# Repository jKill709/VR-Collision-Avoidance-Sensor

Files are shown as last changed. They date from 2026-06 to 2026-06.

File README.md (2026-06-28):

# VR-Collision-Avoidance-Sensor

This README describes the TARGET STATE of this repo.  The project as described is completed, but the documentation proccess is ongoing.  Until this message is removed, docouments listed as components of the repo may bve missing or otherwise missaligned.

## Overview
This repository documents the design and development of an embedded device intended to help VR users avoid physical collisions while immersed in virtual environments.

The project began as an Arduino-based prototype used to validate the core concept and functionality. It was then redesigned around the standalone ATmega328P microcontroller on a breadboard to explore a more integrated embedded implementation. The final iteration moved to a custom PCB design, creating a compact hardware platform suitable for further refinement toward a production-ready device.

The repository contains three documented development stages:

  - Arduino Prototype: Rapid proof-of-concept development using the Arduino platform
  - ATmega328P Breadboard Version: Standalone microcontroller implementation with custom firmware and supporting circuitry
  - Custom PCB Version: Dedicated hardware design including schematics, PCB layout, and final firmware

Each stage includes hardware documentation, firmware, design decisions, and lessons learned throughout the development process.

## Key Features
- Based on ATmega328P using 
- HC-SR04 Ultrasound distance sensor to sense distance to obsticals
- LED and speaker output alerts user
- Final Version has on-board Li-on battery with HW-107 charging module

## Architecture Diagram
```text
VR-Collision-Avoidance-Sensor/
│
├── README.md
├── LICENSE
├── .gitignore
├── arduino_version/
│   ├── README.md
│   ├── src/
│   │   └── Wall_Sensor_0.1.3.ino
│   │   │
│   ├── hardware/
│   │   ├── Circut_Map.png
│   │   └── bom.csv
│   │   
│   └── images/
│       └── various images 
│
├── atmega_breadboard_version/
│   ├── README.md
│   ├── firmware/
│   │   └── BattleBuddy_S_0.1.ino
│   │
│   ├── hardware/
│   │   └── bom.csv
│   │   
│   └── images/
│       └── various images 
│   
│
└── pcb_version/
    ├── README.md
    ├── firmware/
    │   └── Wall_Sensor_0.2.0
    │   
    ├── hardware/
    │   ├── bom.csv
    │   │
    │   └── pcbway_files/
    │       └── various manufacturing assets for PCBway.com
    └── images/
        └── various images 
 ```

## Project Stages

See each stage's README for details:

- Arduino Prototype:  `arduino_version\README.md`
Arduino Prototype
- Breadboard Bare-Metal Implementation:  `atmega_breadboard_version\README.md`
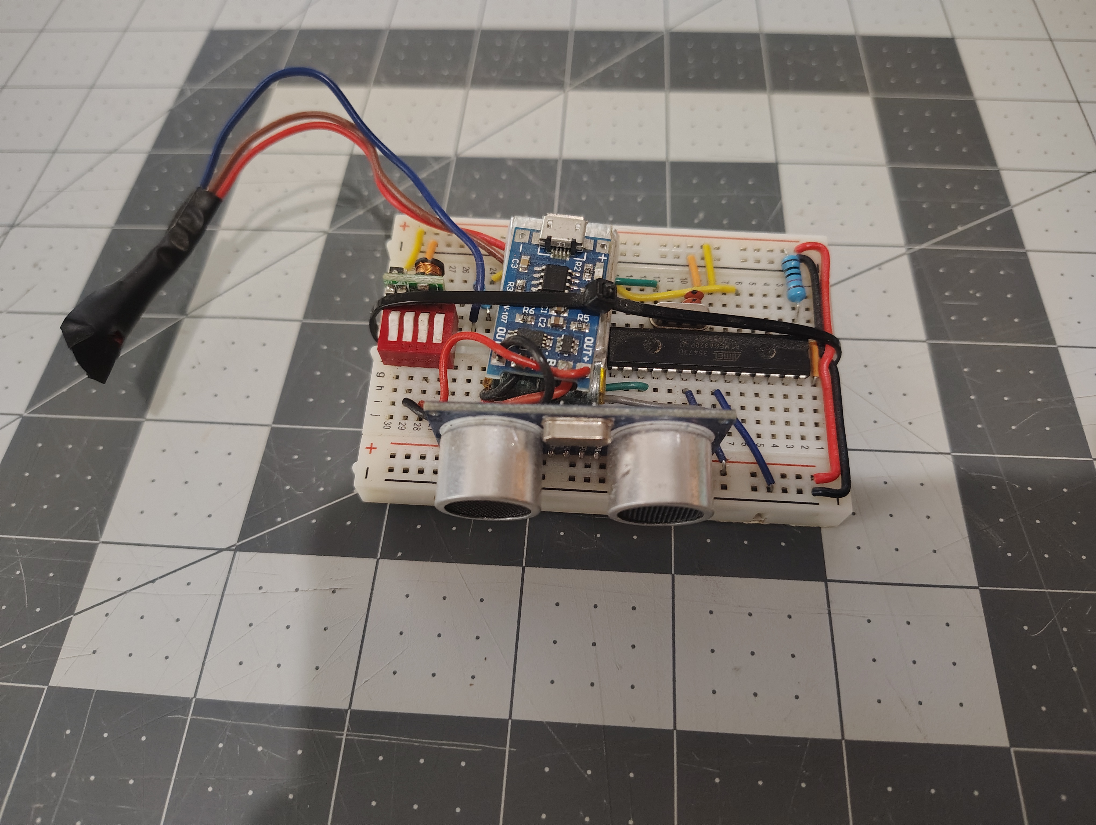
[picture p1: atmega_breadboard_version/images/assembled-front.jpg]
Breadboard Prototype

- PCB Production Prototype Version:  `pcb_version\README.md`
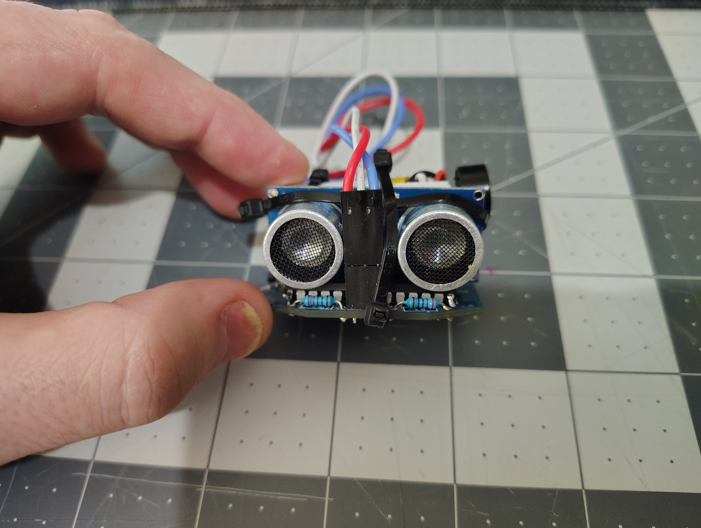
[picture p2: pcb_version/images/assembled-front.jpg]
PCB Prototype


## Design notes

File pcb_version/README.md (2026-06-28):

# Atmega-Breadboard Wall Sensor - "Wall Sensor 0.2"

Arduino Prototype

## Purpose

Build on previous work to create an improved embedded prototype for preventing physical collisions while using VR headsets.

This prototype combines the lessons learned from the Battle Buddy prototype by adding a more complete warning system:

- Visual distance indication using RGB LED feedback
- Audible proximity warning
- Embedded microcontroller design
- Battery-powered operation

This version validates the combined feedback system and transitions to a custom PCB implementation.

---

## Architecture

- Ultrasonic sensor module (HC-SR04) to measure distance
- RGB LED to provide visual feedback based on object proximity
- Piezoelectric buzzer to provide audible proximity warnings
- Atmega328P microcontroller for logic and control
- Li-ion battery for wireless operation
- HW-107 Battery Management Module for charging
- Boost converter to provide regulated 5V operation

The warning system converts distance measurements into a warning intensity value:

- Far distance:
  - Blue LED indication
  - No buzzer

- Medium distance:
  - Color transitions toward red
  - Intermittent warning tone

- Close distance:
  - Red LED indication
  - Maximum warning intensity

---

## Hardware

### Components

| Item | Qty | Reference | Value | Description | Part Number |
|:---|:---:|:---:|:---:|:---|:---|
| 1 | 1 | U1 | | Microcontroller | Atmega328P |
| 2 | 1 | X1 | | Piezoelectric Oscillator | |
| 3 | 2 | C1 C2 | 22 pF | Ceramic Capacitor | |
| 4 | 1 | HC-SR04 | | Ultrasonic Sensor | HC-SR04 |
| 5 | 1 | R1 | 10K Ohms | Resistor | |
| 6 | 1 | D1 | 5V | RGB LED | |
| 7 | 2 | R2 R3 | 220 Ohms | Current-Limiting Resistor | |
| 8 | 1 | PCB | | Custom PCB | |
| 9 | 1 | Boost | 3V to 5V | Boost Converter | |
| 10 | 1 | S1 | | Power Switch | |
| 11 | 1 | HW-107 | | Battery Management Module | HW-107 |
| 12 | 1 | B1 | 3.7V 300 mAh | Li-ion Battery | |
| 13 | 2 | J1 J2 | 2.54mm 2x1 | Header Pins | |
| 14 | 1 | J3 | 2.54mm 3x1 | Header Pins | |
| 15 | 1 | | 2.54mm 2x1 | Male Dupont Connector with Pins | |
| 16 | 1 | | 2.54mm 3x1 | Male Dupont Connector with Pins | |

---

### Hardware Documentation

- Circuit diagram: `hardware/Circuit_Map.png`
- Bill of materials: `hardware/BOM.csv`
- Image of materials: `images/parts-staged.jpg`

---

## Software

The Arduino firmware:

- Runs startup LED sequence to indicate operation
- Reads distance measurements from the HC-SR04 sensor
- Converts measured distance into warning intensity
- Controls RGB LED color and brightness
- Activates buzzer warning based on proximity

Firmware location:  ```firmware/Wall_Sensor_0.2.0/Wall_Sensor_0.2.0.ino```

---

## Design Notes

This version combines the visual feedback concepts explored in Battle Buddy with the warning behavior from the original Wall Sensor prototype.

Changes:

- Uses bare Atmega328P microcontroller instead of Arduino UNO R3
- Adds battery operation with USB charging
- Reintroduces audible warnings for improved situational awareness
- Replaces simple LED indication with RGB distance feedback
- Uses warning intensity as a shared value for multiple output systems

The warning intensity model allows the system to scale naturally:

```
Distance
|
v
Warning Intensity
|
+--> RGB LED
|
+--> Buzzer
```

---

## Limitations

- Detection is limited to a single ultrasonic sensor direction
- Sensor placement and field-of-view limit detection coverage
- LED indication through VR headset optics is functional but not optimized
- Needs a proper enclosure and attatchment mechanism

---

## Lessons Learned

This prototype validated:

- RGB visual feedback provides better distance awareness than simple alarms
- Combining visual and audible feedback improves user awareness
- Bare microcontroller design works for a wearable embedded device
- The design direction is suitable for continued development toward a custom PCB implementation
- The LED used was too small, leading to a structural failure of the solder joints.  Need a better design, oir more skilled solder opperator.

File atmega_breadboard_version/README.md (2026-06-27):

# Atmega-Breadboard Wall Sensor -  "The Battle Buddy"

Arduino Prototype

## Purpose

Build on previous work to create usable prototype of an embedded device to prevent physical collisions while using VR headsets.

This prototype was developed to validate the off-the-shelf modules and design used for this embedded device before transitioning to a Custom PCB implementation.

---

## Architecture

- Ultrasonic sensor module (HC-SR04) to measure distance
- Red and blue LEDs to alert the VR user of detected objects and the estimated distance
- LEDs are ran non destructivly to the optical cavity of the VR headset for user indication
- atmega328p microcontroller for logic and control
- Li-on Battery for wireless operation
- HW-107 Battery Management Module for charging

---

## Hardware

### Components

| Item | Qty | Reference | Value | Description |
|:---|:---:|:---:|:---:|:---|
| 1 | 1 | U1 |  | Microcontroller |
| 2 | 1 | X1 |  | Piezoelectric Oscillator |
| 3 | 2 | C1 C2 | 22 pF | Ceramic Capacitor |
| 4 | 1 | HC-SR04 |  | Ultrasonic Sensor |
| 5 | 1 | R1 | 10K Ohms | Resistor |
| 6 | 1 | D1 | 5V | RGB LED |
| 7 | 2 | R2 R3 | 220 Ohms | Current-Limiting Resistor |
| 8 | 1 |  | 400 Tie-Points | Breadboard |
| 9 | 1 | Boost | 3V to 5V | Boost Converter |
| 10 | 1 | S1 |  | Power Switch |
| 11 | 1 | HW-107 |  | Battery Management Module |
| 12 | 1 | B1 | 3.7V 300 mAh | Li-ion Battery |

### Hardware Documentation

- Circuit diagram: `hardware/Circuit_Map.png`
- Bill of materials: `hardware/BOM.csv`
- Image of materials: `images/parts-staged.jpg`

---

## Software

The Arduino firmware:

- Startup sequence to indicate function
- Reads distance measurements from the HC-SR04 sensor
- Activates visual alerts when an object is detected

Firmware location:

```
<!-- firmware/BattleBuddy_S_0.1/BattleBuddy_S_0.1.ino -->
```

---

## Design Notes

This version focuses on design validation before committing to a PCB design.

Changes:
- Uses bare microprocessor instead of Arduino UNO R3
- Adds battery operation with USB charging, allowing alpha testing
- Swaps buzzer for a more nuanced LED signaling system: uses 2 colors to show distance to detection

Limitations:
- Only breadboarded, so not rugged enough for beta testing
- Only shows detection in current direction
- Not optimized for a final embedded product
- Sub-optimal switch choice.  I used what I had.
- Indicator LED is run nondestructively, but this is not the best user experience  (see `images/indicator-installed.png`)

---

## Lessons Learned

This prototype validated:

- Can perform it's basic function in actual use (Alpha testing was successful!)
- Bare microprocessor design works
- Warning feedback mechanisms were improved
- Suitable for wearing as a VR headset accessory

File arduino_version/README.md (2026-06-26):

# Arduino-Based Wall Sensor

Arduino Prototype

## Purpose

Use the Arduino microcontroller development platform to investigate the creation of an embedded device to prevent physical collisions while using VR headsets.

This prototype was developed to validate the core concept before transitioning to a standalone ATmega328P implementation.

---

## Architecture

- Ultrasonic sensor module (HC-SR04) to measure distance
- LED and passive speaker to alert the VR user of detected objects
- Arduino UNO R3 for logic and control
- Potentiometer to adjust detection sensitivity for development
- Serial output over USB for validation and debugging

---

## Hardware

### Components

| Item | Qty | Reference | Value | Description |
|:---|:---:|:---:|:---:|---:|
| 1 | 1 |  |  | Arduino UNO R3 Development Board |
| 2 | 1 | HC-SR04 |  | Ultrasonic Sensor |
| 3 | 1 | BZ1 |  | Passive Buzzer |
| 4 | 1 | D1 | 5V | Green LED (ON/OFF Indicator) |
| 5 | 1 | D2 | 5V | Red LED (Warning LED) |
| 6 | 1 | Pot1 | 10K Ohms | Potentiometer |
| 7 | 2 | R1, R2 | 220 Ohms | Current-Limiting Resistor|
| 8 | 1 |  | 170 Tie-Points | Breadboard |

### Hardware Documentation

- Circuit diagram: `hardware/Circuit_Map.png`
- Bill of materials: `hardware/BOM.csv`

---

## Software

The Arduino firmware:

- Reads distance measurements from the HC-SR04 sensor
- Compares distance against an adjustable warning threshold
- Activates visual and audible alerts when an object is detected
- Provides serial output for testing and calibration

Firmware location:

```
src/Wall_Sensor_0.1.3.ino
```

---

## Design Notes

This version prioritized rapid development and concept validation.

Advantages:
- Fast iteration using the Arduino ecosystem
- Easy debugging through USB serial output
- Minimal hardware setup

Limitations:
- Requires power cord
- Dependent on Arduino development board
- Not optimized for a final embedded product

---

## Lessons Learned

This prototype validated:

- Ultrasonic sensing was suitable for collision detection
- Warning feedback mechanisms were effective
- A standalone microcontroller implementation was feasible
- A threshold value was determined by using potentiometer and serial output, and can now be hardcoded in the next iteration

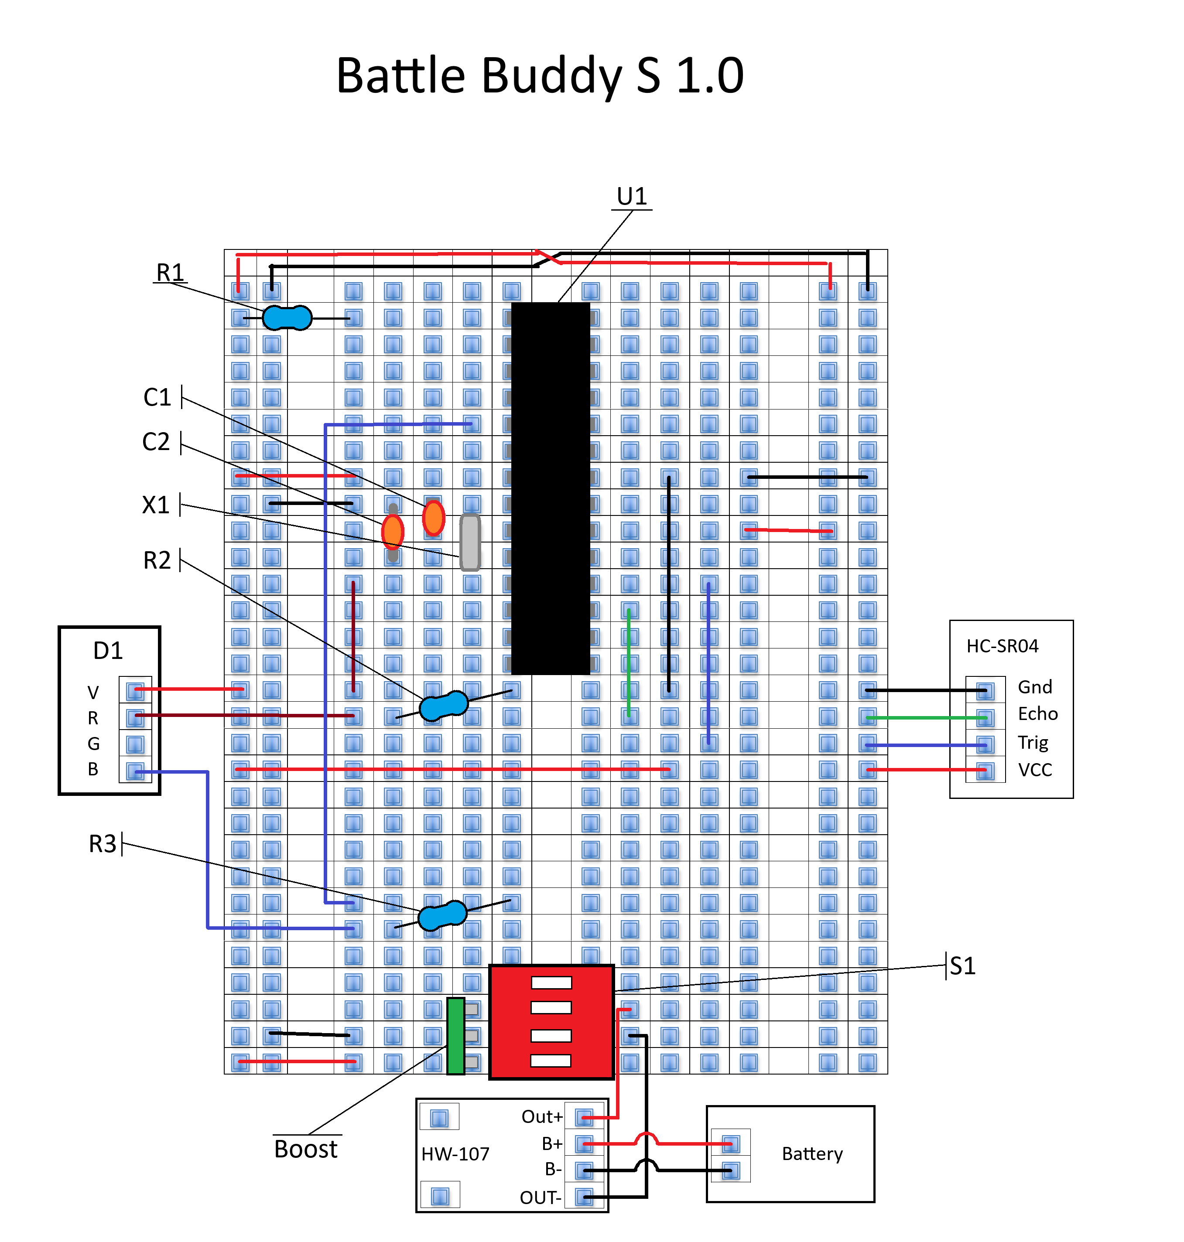
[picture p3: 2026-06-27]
atmega_breadboard_version/hardware/circut-map.png

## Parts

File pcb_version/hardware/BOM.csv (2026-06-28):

Item | Qty | Reference | Value | Description | Part Number
1 | 1 | U1 |  | Microcontroller | Atmega328P
2 | 1 | X1 |  | Peizioelectric Oscilator
3 | 2 | C1 C2 | 22 pF | Ceramic Capacitor
4 | 1 | HC-SR04 |  | Ultrasonic Sensor | HC-SR04
5 | 1 | R1 | 10K Ohms | Resisitor
6 | 1 | D1 | 5V | RGB LED
7 | 2 | R2 R3 | 220 Ohms | Current-Limiting Resistor
8 | 1 | PCB |  | Custom PCB
9 | 1 | Boost | 3v to 5 v | Boost Converter
10 | 1 | S1 |  | Power Switch
11 | 1 | HW-107 |  | Battery Management Module | HW-107
12 | 1 | Battery | 3.7 v 300 mAh | Li-ion Battery
13 | 2 | J1 J2 | 2.45mm 2x1 | Header Pins
14 | 1 | J3 | 2.45mm 3x1 | Header Pins
15 | 1 |  | 2.45mm 2x1 | Male Dupont Connector w/ Pins
16 | 1 |  | 2.45mm 3x1 | Male Dupont Connector w/ Pins

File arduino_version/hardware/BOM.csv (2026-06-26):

Item | Qty | Reference | Value | Description | Part Number | Notes
1 | 1 |  |  | Arduino UNO R3 Development Board
2 | 1 | HC-SR04 |  | Ultrasonic Sensor | HC-SR04
3 | 1 | Buzzer |  | Passive Buzzer
4 | 1 | D1 | 5V | Green LED |  | ON/OFF Indicator
5 | 1 | D2 | 5V | Red LED |  | Warning LED
6 | 1 | Pot1 | 10K Ohms | Potentiometer
7 | 2 | R1 R2 | 220 Ohms | Current-Limiting Resistor
8 | 1 |  | 170 Tie-Points | Breadboard

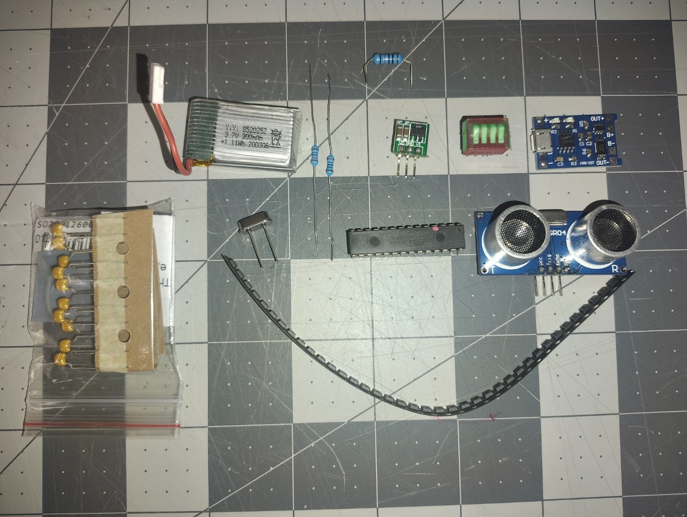
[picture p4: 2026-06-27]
atmega_breadboard_version/images/parts-staged.jpg

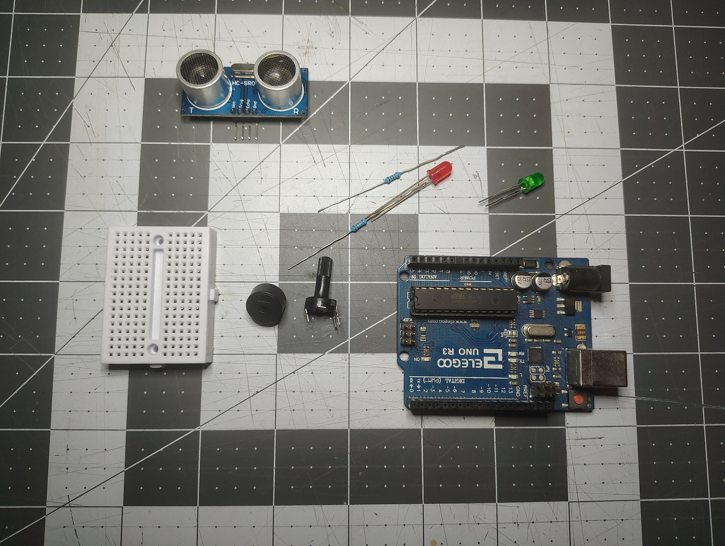
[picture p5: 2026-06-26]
arduino_version/images/parts-staged.jpg

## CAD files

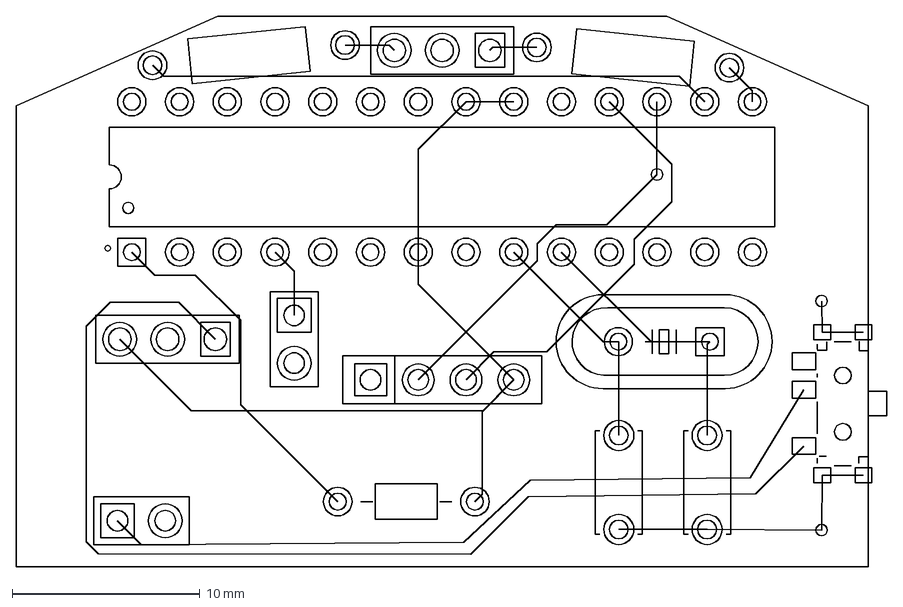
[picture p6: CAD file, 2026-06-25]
pcb_version/hardware/pcbway_files/Board Model v1.dxf
46.3 x 29.3 mm

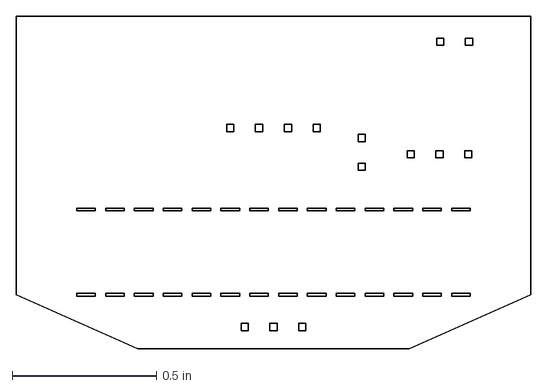
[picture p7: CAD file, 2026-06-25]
pcb_version/hardware/pcbway_files/Board.dxf
1.79 x 1.15 in

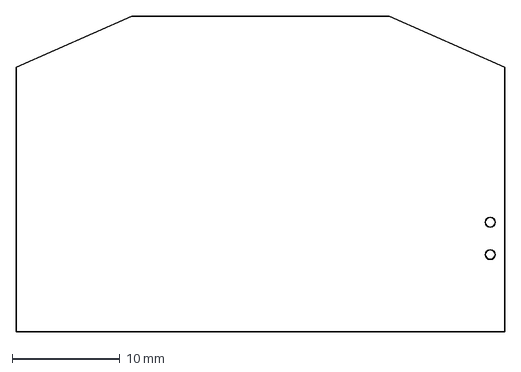
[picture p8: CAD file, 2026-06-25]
pcb_version/hardware/pcbway_files/Board Model, Holes v1.dxf
45.3 x 29.3 mm

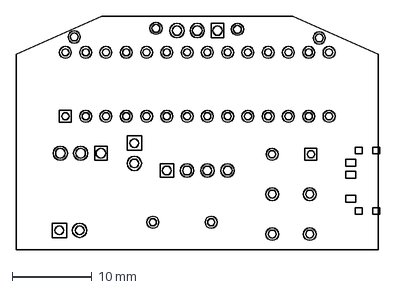
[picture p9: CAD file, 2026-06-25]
pcb_version/hardware/pcbway_files/Board Model, Copper v1.dxf
45.5 x 29.3 mm

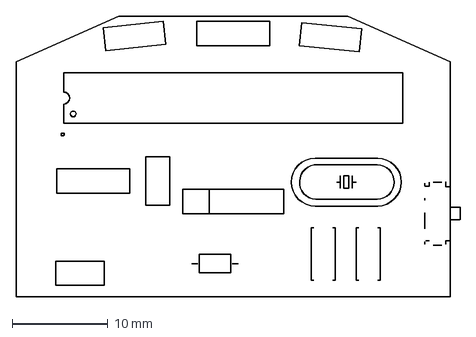
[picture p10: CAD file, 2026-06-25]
pcb_version/hardware/pcbway_files/Board Model, Silkscreen v1.dxf
46.3 x 29.3 mm

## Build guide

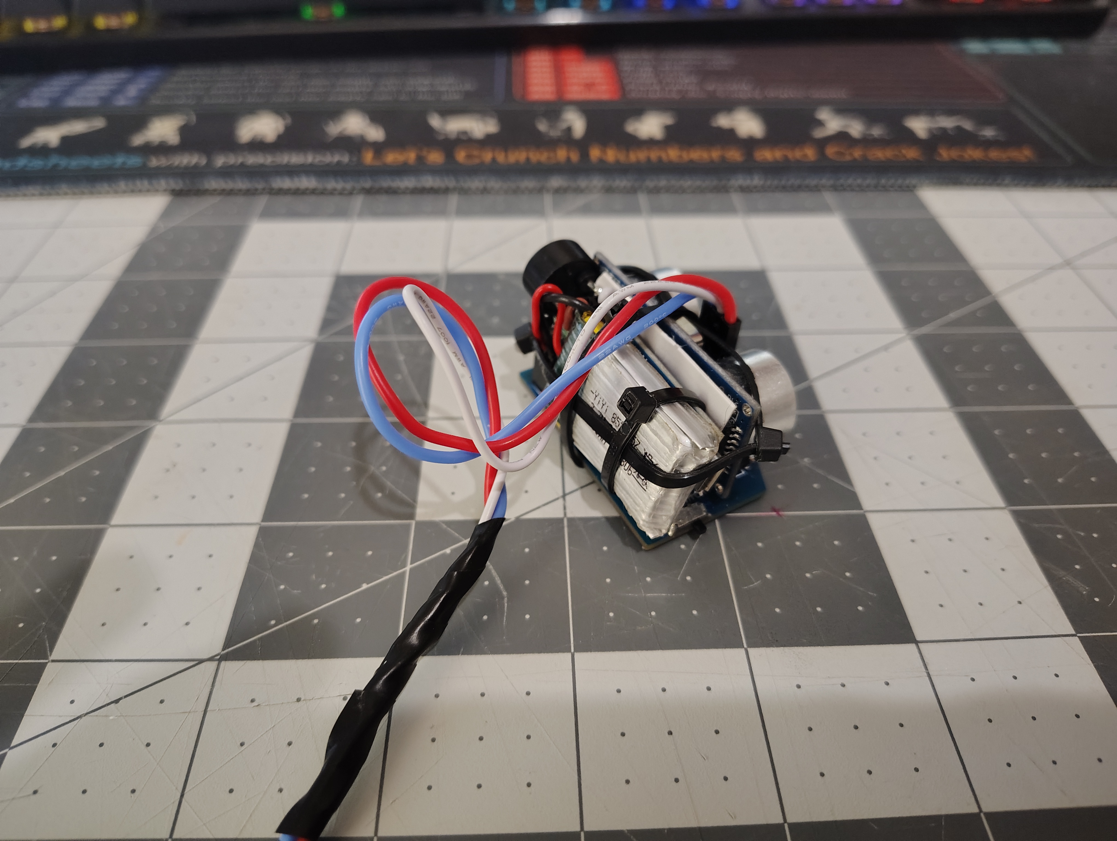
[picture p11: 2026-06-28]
pcb_version/images/assembled-rear-2.jpg

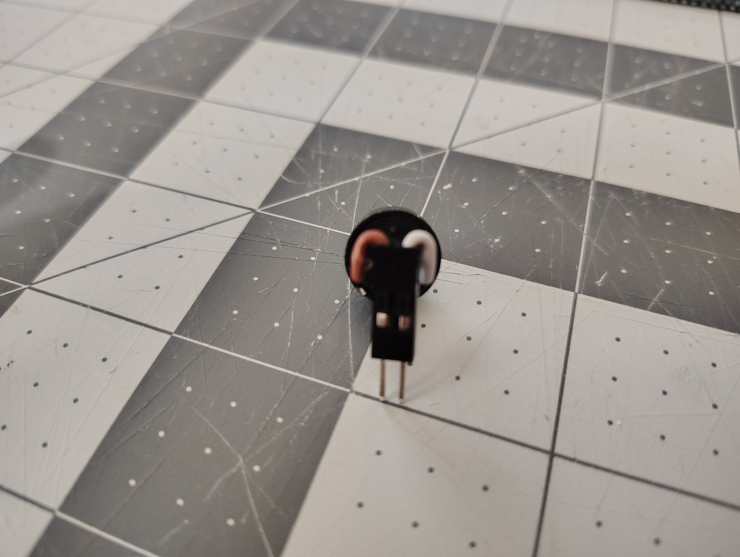
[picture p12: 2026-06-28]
pcb_version/images/speaker-subassembly-rear.jpg

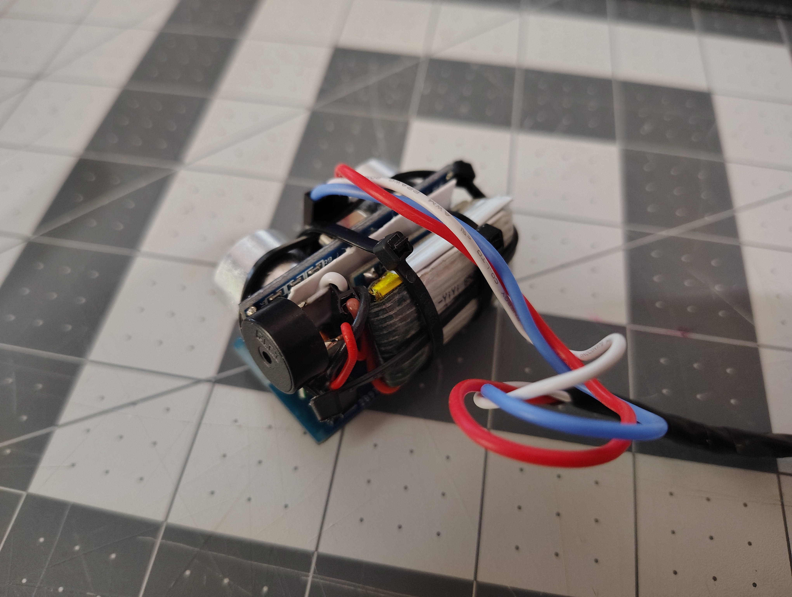
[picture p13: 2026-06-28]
pcb_version/images/assembled-rear-1.jpg

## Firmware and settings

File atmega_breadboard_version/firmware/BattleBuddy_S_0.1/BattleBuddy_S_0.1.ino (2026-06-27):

/*      Wall Sensor v0.1.04
 *      
 *      Last Modified 1/10/20
 *
 *      Ultrasonic proximity sensor with RGB LED visual feedback.
 *      As an object approaches, the LED intensity increases.
 *      Includes startup animation sequence.
 */

#include <SPI.h>
#include <Wire.h>


// Pin Numbers            
#define redLED 5          // Red LED Pin          | Must Be PMW
#define blueLED 3         // Blue LED Pin         | Must Be PMW
#define sensorTrig 12     // HC-SR04 Trigger Pin  | no requirements
#define sensorEcho 11     // HC-SR04 Echo Pin     | no requirements

// System Settings
#define distMin 30                // Min distance for LED fade, in cm
#define distMax 64                // Max distance for LED fade, in cm
#define maxIntensity 0.125 * .6   // Maximum LED brightness scaling factor.  Could be replaced with larger resistor than BOM spec.
#define cycleTime 50              // Sensor update interval in milliseconds

// Sensitivity multiplier used to adjust effective sensor range
float sensitivity = 1.00;

// Loop Control
// Stores the next time the sensor should be sampled
long nextCycleTime;

// 
//
// Setup
void setup() {  

  // Configure LED pins as outputs
  pinMode(redLED, OUTPUT);
  pinMode(blueLED, OUTPUT);
  pinMode(sensorTrig, OUTPUT);
  pinMode(sensorEcho, INPUT);

  // Configure ultrasonic sensor pins
  introSeq();
    

  // Schedule first sensor reading
  nextCycleTime = millis() + cycleTime;
}

//
//
// Main Loop
void loop() {

  // Timing control.  Only samples the sensor after cycleTime has elapsed.
  if(millis() >= nextCycleTime) {

    // Schedule next sensor reading
    nextCycleTime = millis() + cycleTime;

    // Read distance and update LED output
    sampleSensor();
  }
}

//
//
// Converts distance value into LED intensity value
//
// Close distance  = brighter LED
// Far distance    = dimmer LED
//
// Returns PWM value from 0-255
int distanceToIntensity(long distance) {

  // Maps measured distance range into LED brightness range
  // constrain prevents values outside the valid PWM range
  return constrain(map(distance, distMin * sensitivity, distMax * sensitivity, 255 * maxIntensity, 0), 0, 255 * maxIntensity);
}

//
//
//  Reads ultrasonic sensor and updates LED brightness
void sampleSensor() {

  // Send ultrasonic trigger pulse
  digitalWrite(sensorTrig, LOW);
  delayMicroseconds(2);

  digitalWrite(sensorTrig, HIGH);
  delayMicroseconds(10);

  digitalWrite(sensorTrig, LOW);
  delayMicroseconds(2);

  // Measure echo return time and convert to distance
  // pulseIn returns microseconds
  // Conversion factor converts time into centimeters
  //
  // LED brightness is inverted:
  // closer object = higher intensity
  // farther object = lower intensity
  analogWrite(redLED, 255 - (distanceToIntensity(pulseIn(sensorEcho, HIGH, 400000) * (100.00 / 5882.00))));
}

//
//
// Intro Sequence
//
//    A/V sequence for flashy bootup
void introSeq() {

  // Turn on red LED
  analogWrite(redLED, 255);

  // Turn off blue LED
  analogWrite(blueLED, 0);

  delay(200);

  // Turn on blue LED
  analogWrite(blueLED, 255);

  delay(800);

  // Fade both colors down
  for (int i = 0; i < 256; i++) {

    // Gradually reduce LED intensity
    analogWrite(redLED, 255 - i/16);
    analogWrite(blueLED, 255 - i);
    
    delay(3);
  }

  // Leave LEDs fully illuminated after startup
  analogWrite(redLED, 255);
  analogWrite(blueLED, 255);  
}

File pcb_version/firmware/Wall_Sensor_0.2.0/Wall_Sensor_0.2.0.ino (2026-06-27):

#include <SR04.h>
#include <pitches.h>

/*      Wall Sensor v0.1.04
 *      
 *      Last Modified 1/24/19
 *
 *      Ultrasonic proximity warning system.
 *      Uses distance measurement to control:
 *      - RGB LED warning intensity
 *      - Audible buzzer feedback
 *
 *      As an object approaches:
 *      - LED color shifts from blue toward red
 *      - Warning tone increases in duration
 */
 
// Pin Numbers
#define redLED 9          // Red LED Pin          | Must Be PMW
#define blueLED 10        // Blue LED Pin         | Must Be PMW
#define warningBuzzer 2   // Buzzer Pin           | no requirements
#define ussTrigPin 12     // HC-SR04 Trigger Pin  | no requirements
#define ussEchoPin 11     // HC-SR04 Echo Pin     | no requirements

// System Settings
int threshold = 122;      // Distance at which warning begins, in cm
int cycleTime = 100;      // Main update cycle time, in ms

// Instantiate Sensor Object
SR04 usSensor = SR04(ussEchoPin,ussTrigPin);

//
//
// Setup
void setup() {  

  // Configure output pins
  pinMode(redLED, OUTPUT);
  pinMode(blueLED, OUTPUT);
  pinMode(warningBuzzer, OUTPUT);

  // Run startup LED animation
  introSeq();
}

//
//
// Intro Sequence
//
//    A/V sequence for flashy bootup
void introSeq() {

  // Start with blue LED fully on
  analogWrite(redLED, 0);
  analogWrite(blueLED, 255);

  delay(200);

  // Turn blue off
  analogWrite(blueLED, 0);

  delay(800);

  // Fade blue LED back in
  for (int i = 0; i < 256; i++) {
    analogWrite(blueLED, i);
    delay(3);
  }
  
}

//
//
// beepCalc
//
//    Return a float between 0 and 1 indicating how much of each 
//    cycle should be spent with the buzzer on
//
//    0 = no warning
//    1 = continuous warning
//
//    Warning increases as distance decreases
float beepCalc (float dist, float threshold) {

  // Distance ratio relative to warning threshold
  float a = dist/threshold;

  // Maximum warning when object is closer than half threshold
  if (dist < .5 * threshold) {
    return 1;

  // No warning when outside threshold distance
  } else if (dist > threshold) {
    return 0;

  // Scale warning intensity between half threshold and threshold
  } else {
    return pow((-2 * dist/threshold) + 2, 1);   //<-- WTF? X^1?
  }
}

//
//
//  lightAdj
//
//  Set the color of the LED based on warningInstensity
//
// warningIntensity:
// 0 = blue / no warning
// 1 = red / maximum warning
//
// Adjusts both active and inactive LED channels
void lightAdj(float warningIntensity) {

  int onLightPin;
  int offLightPin;

  int onLightVal;
  int offLightVal;


  // Calculate brightness of active LED channel
  onLightVal = 255 * (0.8 * (pow(warningIntensity * 2 - 1, 4)) + 0.2);

  // Calculate brightness of inactive LED channel
  offLightVal = 255 * ((-pow(warningIntensity - 0.5, 2) * 5) + 0.2);


  // Prevent negative PWM values
  if (offLightVal < 0) {
    offLightVal = 0;
  }


  // Select LED color based on warning intensity
  if (warningIntensity > .5) {

    // Higher warning = red dominant
    onLightPin = redLED;
    offLightPin = blueLED;

  } else {

    // Lower warning = blue dominant
    onLightPin = blueLED;
    offLightPin = redLED;
  }


  // Apply calculated LED brightness
  analogWrite(onLightPin, onLightVal);
  analogWrite(offLightPin, offLightVal);
}

//
//
// Main Loop
void loop() {

  // Read distance from ultrasonic sensor
  int dist = usSensor.Distance();

  // Convert distance into warning intensity
  float warningIntensity = beepCalc(dist, threshold);

  // Convert warning intensity into buzzer duration
  int beepLength = cycleTime * warningIntensity;
  

  // Update RGB LED output
  lightAdj(warningIntensity);


  // Play warning tone if object is within range
  if (warningIntensity > 0){

    // Tone duration increases as object gets closer
    tone(warningBuzzer, NOTE_C4, beepLength);
  }

  // Wait before next sensor update
  delay(cycleTime);
}

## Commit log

2026-06-25 Adjusted file structure to reflect 'Evolution of Project' Presentation style (work in progress)
    [Board Model v1.dxf, Board Model, Copper v1.dxf, Board Model, Holes v1.dxf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]
2026-06-25 Further adjusted existing files into intended file structure
    [Board Model v1.dxf, Board Model, Copper v1.dxf, Board Model, Holes v1.dxf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]
2026-06-25 Renamed repo from 'Wall Sensor' to 'VR-Collision-Avoidance-Sensor'
2026-06-25 Added blank BOMs for each project stage
    [BOM.csv, Blank BOM.csv]
2026-06-26 Added enhanced 'arduino_version' documentation
    [BOM.csv, Blank BOM.csv]
2026-06-27 added enhanced 'atmega_breadboard_version' documentation
    [BOM.csv]
2026-06-27 Updated main README and PCB version Documentation
    [BOM.csv]
2026-06-28 Added more enhanced documentation for 'pcb_version'
    [BOM.csv, Board Model v1.dxf, Board Model, Copper v1.dxf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]
2026-06-28 Changed photo in 'pcb_version\README.md and fixed typo in photo name
